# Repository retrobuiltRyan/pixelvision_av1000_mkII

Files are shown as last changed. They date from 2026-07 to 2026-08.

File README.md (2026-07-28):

# PixelVision_AV-1000_MkII

Desktop sized multi-format video display monitor for HDMI and legacy analog video input with built-in speakers.
Watch the video: (assembly section @14:51) <br>
<a href="https://youtu.be/h4x5J-W30Yo" target="_blank">
  Watch the video on YouTube
</a> ## https://youtu.be/MTYouu-5v1Q <br> 
Monitor Assy <br>
## Hardware Overview

| Specification | Details |
|---|---|
| Viewable Size | 9.7” [4:3 ratio] |
| Input Signals | HDMI [2048×1536]; VGA [1920×1080]; YPbPr, S-video, Composite [480p] |
| Audio Input/Output | Analog 3.5mm stereo |
| Speaker Output | Stereo (5 watt) |
| Power Consumption | 10 watts (2w standby) |
| Dimensions (W × H × D) | 248 × 205 × 192 mm (9.76 × 8.07 × 7.56 inches) |
| Weight | 1350 g |

### IPS [iPad 3/4] Panel Details

| Specification | Details |
|---|---|
| Pixel Density | 264 PPI |
| View Angle | 89/89/89/89 (Typ.) (CR ≥ 10) |
| Frequency | 60 Hz |
| Panel Type / Model | a-Si TFT-LCD, LCM / LP097QX1-SPC1 |
| Brightness | 440 cd/m² |

## Electrical Diagram
 <br>

## Bill of Materials
| Item | Description | Vendor Link | Cost/each (USD) | Qty | Line Total (USD) |
|---|---|---|---:|----:|---:|
| 1 alt | Speaker Dayton Audio CE32A-4 1-1/4" | [parts-express](https://www.parts-express.com/Dayton-Audio-CE32A-4-1-1-4-Mini-Speaker-4-Ohm-285-103) | 3.58 | 2 | $7.16 |
| 1 | Speaker Visaton FR7-4 2.5" | [parts-express](https://www.parts-express.com/Visaton-FR7-4-2-1-2-Full-Range-Driver-4-Ohm-292-638) | 6.47 | 2 | $12.94 |
| 2 | LCD 9.7" 2048×1536 HDMI | [aliexpress](https://www.aliexpress.us/item/3256803412961622.html) | 50.60 | 1 | $50.60 |
| 3 | Scan Line Converter | [aliexpress](https://www.aliexpress.us/item/3256805577379481.html) | 47.64 | 1 | $47.64 |
| 4 | M2.6 × 10mm Thread Forming Screw | [aliexpress]([#](https://www.aliexpress.us/item/3256807955659503.html)) | 0.04 | 70 | $2.80 |
| 5 | M3 × 6mm Button Head Screws | any | 0.03 | 3 | $0.09 |
| 6 | M3 × 11mm F/F Standoff | any | 0.10 | 3 | $0.30 |
| 7 | Filament, 1 gram PLA | any | 0.02 | 877 | $17.54 |
| 8 | Audio Amp PAM8406 | [aliexpress](https://www.aliexpress.us/item/3256807320222817.html) | 6.48 | 1 | $6.48 |
| 9 | M6 × 30 Steel Phillips Flat Head Screw | [mcmaster](https://www.mcmaster.com/91420A438/) | 0.13 | 1 | $0.13 |
| 10 | M6 Nylon Lock Nut | [mcmaster](https://www.mcmaster.com/90631A114/) | 0.08 | 1 | $0.08 |
| 11 | HDMI Super Slim Cable, 1 ft | [parts-express](https://www.parts-express.com/Audtek-TS1-1-ft.-Super-Slim-Ultra-HD-HDMI-2.0-Cable-4K60-Hz-HDR-YCbCr-444-18-Gbps-180-1318) | 3.97 | 1 | $3.97 |
| 12 | Audio Cable, Slim, 1 ft, 3.5mm | [parts-express](https://www.parts-express.com/3.5mm-Male-to-Male-Slim-Plug-Shielded-Audio-Cable-1-ft.-240-051) | 1.59 | 1 | $1.59 |
| 13 | DC Power Jack, Panel Mount (2.1 × 5.5mm) | [aliexpress](https://www.aliexpress.us/item/3256808307457555.html) | 0.45 | 2 | $0.90 |
| 14 | Rocker Switch panel mount (19 x 13mm) | [parts-express](https://www.parts-express.com/SPST-Miniature-Rocker-Switch-060-670) or [digikey](https://www.digikey.com/en/products/detail/e-switch/RA11131121/2720267) | 1.40 | 1 | $1.40 |
| 15 | Audio PCB (optional, but helpful) | custom DIY | 2.00 | 1 | $2.00 |
| 16 | Power PCB (optional, but helpful) | custom DIY | 3.00 | 1 | $3.00 |
| 17 | Rubber Feet (2 × 10mm), Round | [aliexpress](https://www.aliexpress.us/item/3256801658571146.html) | 0.10 | 4 | $0.40 |
| 18 | 12V 3A DC Power Supply (2.1 × 5.5mm) | [parts-express](https://www.parts-express.com/12V-DC-3A-AC-Adapter-Power-Supply-with-2.1-x-5.5mm-Center-Positive-Tip-with-Polarized-AC-Co-129-1204) | 7.00 | 1 | $7.00 |
| 19 | Perler Beads (plastic M2.5 washers) | any | 0.01 | 30 | $0.30 |
| 20 | Compression Spring, ~10mm OD, 25-35mm length, ~0.8mm wire dia, SS | any | 0.50 | 1 | 0.50|
| 21 | Electronics incidentals: wire, heat shrink, that one drop of hot glue | [any](#) | 1.00 | 1 | $1.00 |
| | **TOTAL** | | | | **$167.82** |

## Special Tools
You need a long reach (min 100mm) Torx T8 drive [like this](https://www.aliexpress.us/item/3256805848633499.html). If you source different M2.6 thread forming screws, then you need that matching (min 100mm long) bit drive tool .
 <br>

## 3D Printing 
These parts need to be printed. 15% infill, tree supports where applicable. <br>
*The two thin brackets that push the LCD against the front bezel are a mirrored pair. You need to clone + mirror in your slicer.* <br>

<br>

 *Critical Tip!* <br>  Absolutely block supports in blind screw holes. 


| Filament totals | Grams (g) | Cost/gram | Line total | Print time (hrs) |
|---|---:|---:|---:|---:|
| Body Rear | 416 | $0.02 | $8.32 | 14 |
| Body Front Bezel | 146 | | $2.92 | 3.75 |
| Yoke bulge | 65 | | $1.30 | 2.75 |
| LCD bracket | 42 | | $0.84 | 1 |
| Electronics Mount | 26 | | $0.52 | 1 |
| IO panel | 16 | | $0.32 | 0.75 |
| Speaker, LCD brackets (x2) + buttons | 36 | | $0.72 | 1.55 |
| Swivel Base | 130 | | $2.60 | 5 |
| **Total** | **877** | | **$17.54** | **29.8** |

## PCBs 
(optional, but very helpful with internal wiring and matching the build shown in the video)
P1130062

#### Fits this LCD panel (ipad 3/4 replacement screen):


## Support Me
If you want to support me and future work consider a [donation](https://www.paypal.com/donate/?hosted_button_id=JNT5P3N3XAK2E).
**You can also purchase a basic [fastener kit for this project](https://www.ebay.com/itm/147443247342).** This directly supports me, saves you some time sourcing parts, and clears out my surplus junk from the design process. 
small
<br>
Need a full-time hardware engineer? Hire me. DM me on twitter [@retrobuiltgames](https://x.com/retrobuiltgames)

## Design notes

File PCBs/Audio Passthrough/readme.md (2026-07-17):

Place all three kicad files (.kicad_pcb, .kicad_sch, .kicad_pro) in a folder of the same name. Open the project file (.kicad_pro) with KiCad.

- **2-in-1 PCB Application**
  - **Option 1:** TRS audio passthrough
  - **Option 2:** Ground loop isolator
  <br>

For the PixelVision AV-1000, we just need a simple 3.5mm TRS audio jack passthrough to reroute signals in the monitor enclosure. The bottom jumpers on the PCB must be soldered if this PCB is being used as a straight audio passthrough only. The board also doubles as a ground loop isolator using not-so-great audio transofrmers. (I use a ground loop isolator when I pull analog audio from a Raspberry Pi 3, which has some noisy analog audio.) From my 'raw ear listening' testing, you can't tell how the cheap these parts are. The 65mm diameter speakers cannot output freq under 100Hz, which doesnt matter as the cheap audio transformers cannot pass anything below 200Hz. That sub 200Hz roll-off numbers might be a lie one the datasheet- the parts are so cheap. 

Ground Loop isolator audio passthrough PCB <br>
Ground Loop isolator audio passthrough PCB 2 <br>

P1120733 <br>

| Reference | Quantity | DigiKey P/N |
|---|---:|---|
| J1, J2 | 2 | CP1-3523N-ND |

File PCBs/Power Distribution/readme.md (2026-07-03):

Place all three kicad files (.kicad_pcb, .kicad_sch, .kicad_pro) in a folder of the same name. Open the project file (.kicad_pro) with KiCad.

Power Dist PCB

Handles input power distribution, power on/off switching, and power rerouting. Board includes two 5 V linear regulators and one adjustable buck converter.

 ## Bill of Materials
 | Reference | Value | Qty | DigiKey P/N |
|-----------|-------|----:|-------------|
| C1, C3, C5 | 0.22uF 50V CER | 3 | 445-2283-1-ND |
| C2, C4, C6 | 0.1uF 50V | 3 | 1276-1068-1-ND |
| D1 | DIODE STANDARD 50V 5A SMC | 1 | S5AC-FDICT-ND |
| J1, J2, J3, J4, J5, J6, J7 | Screw_Terminal_2_P3.50mm | 7 | 732-2747-ND |
| R3, R5, R6 | 330 | 3 | 311-330FRCT-ND |
| U2 | LM7809_TO220 | 1 | BA7809FP-E2CT-ND |
| U3 | L7805 | 1 | 497-7255-1-ND |
| U4 | Adj Buck Converter | 1 | [AliExpress](https://www.aliexpress.us/item/3256805684077964.html) |

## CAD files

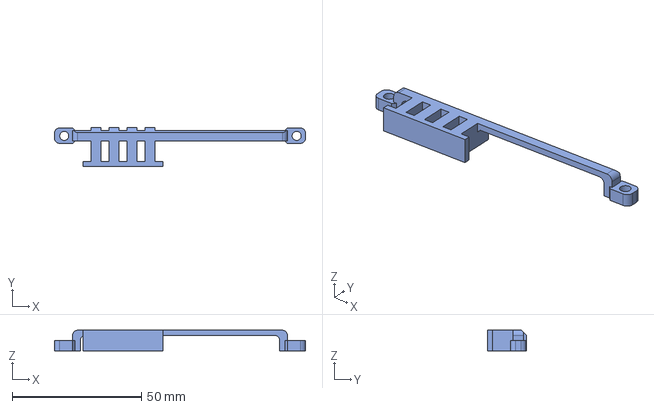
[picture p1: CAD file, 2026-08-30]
STEP files/PixelVision AV-1000MkII v1.0 Swivel Base - LightPipe clip.step
97.2 x 15.2 x 8.00 mm

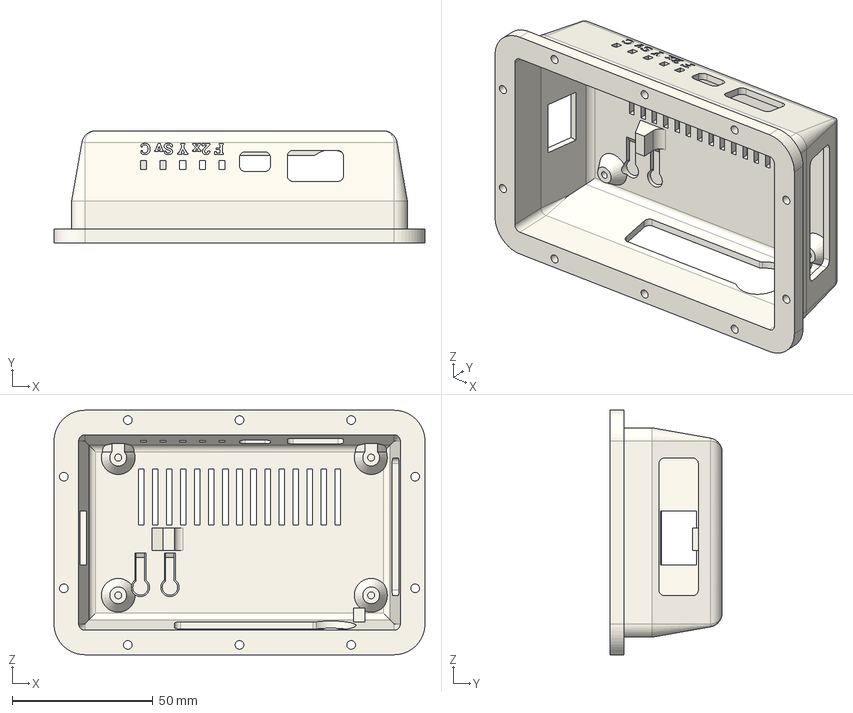
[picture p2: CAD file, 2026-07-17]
STEP files/PixelVision AV-1000MkII v1.0 - Yoke Buldge.step
132.0 x 40.0 x 87.0 mm

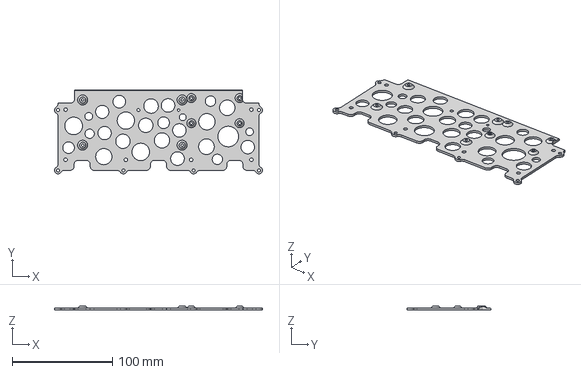
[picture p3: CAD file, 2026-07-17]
STEP files/PixelVision AV-1000MkII v1.0 - Electronics mount.step
207.0 x 83.4 x 4.00 mm

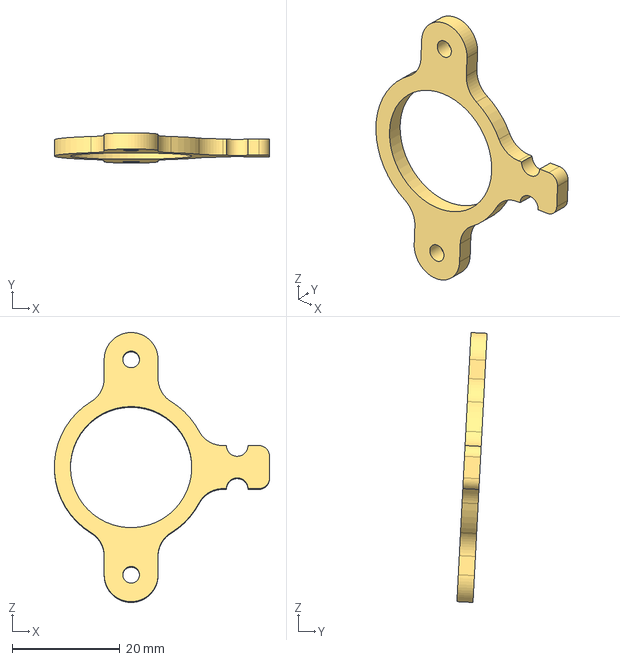
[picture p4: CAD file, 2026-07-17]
STEP files/PixelVision AV-1000MkII v1.0 - Speaker Bracket Small.step
39.9 x 5.61 x 50.1 mm

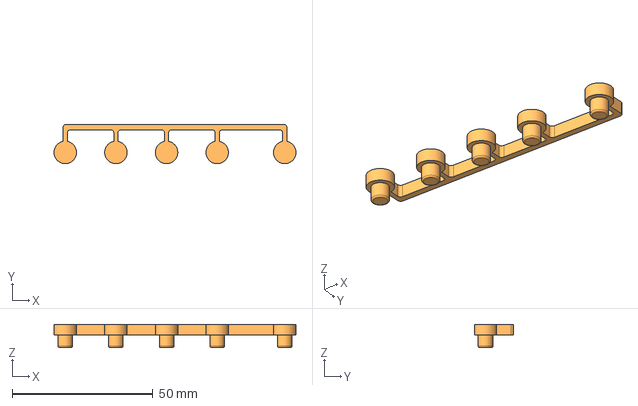
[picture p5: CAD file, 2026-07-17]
STEP files/PixelVision AV-1000MkII v1.0 - Buttons finglonger.step
86.0 x 14.0 x 8.25 mm

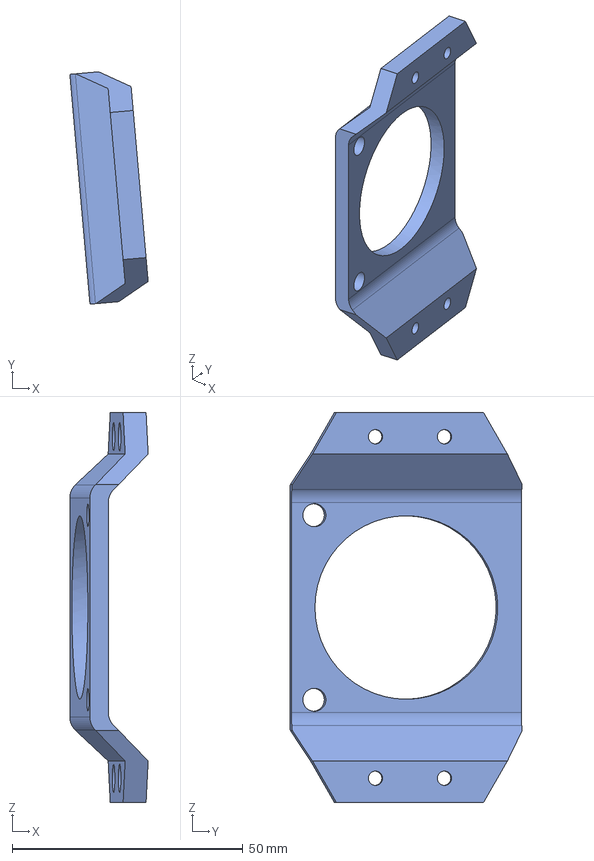
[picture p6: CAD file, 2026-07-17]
STEP files/PixelVision AV-1000MkII v1.0 - Speaker Bracket Large.step
17.0 x 50.4 x 84.5 mm

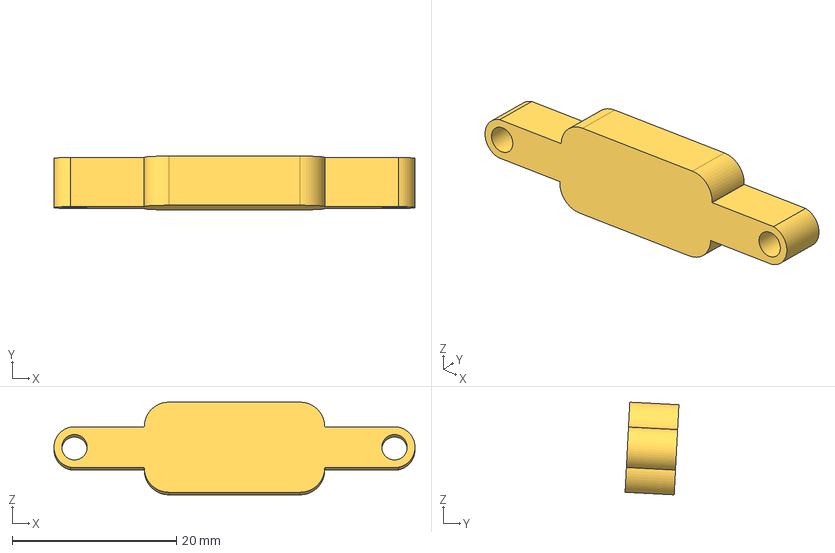
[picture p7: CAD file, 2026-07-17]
STEP files/PixelVision AV-1000MkII v1.0 - LCD ribbon pcb bracket.step
44.0 x 6.57 x 11.3 mm

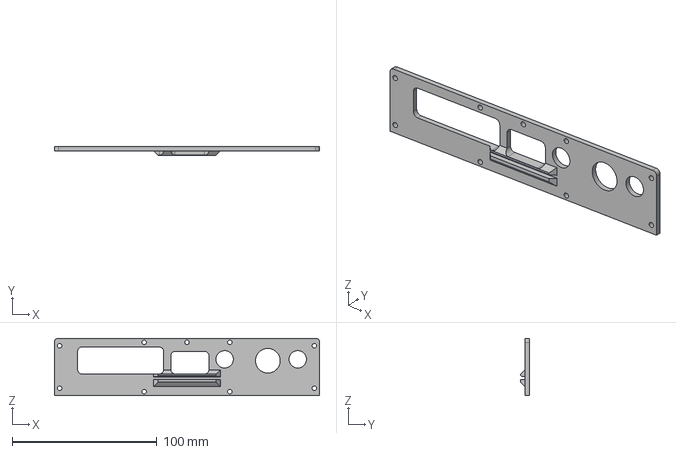
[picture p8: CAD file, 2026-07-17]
STEP files/PixelVision AV-1000MkII v1.0 - IO Cover Plate (rear).step
182.9 x 6.00 x 39.6 mm

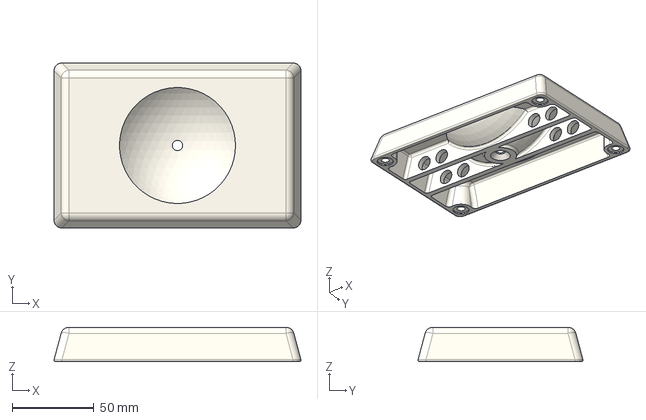
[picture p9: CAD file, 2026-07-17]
STEP files/PixelVision AV-1000MkII v1.0 Swivel Base - Bot.step
150.6 x 100.6 x 21.0 mm

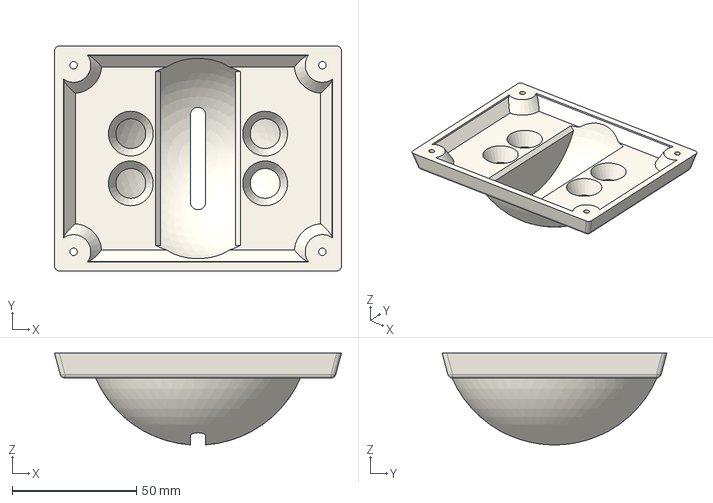
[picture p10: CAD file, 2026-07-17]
STEP files/PixelVision AV-1000MkII v1.0 Swivel Base - Top.step
115.4 x 90.4 x 36.9 mm

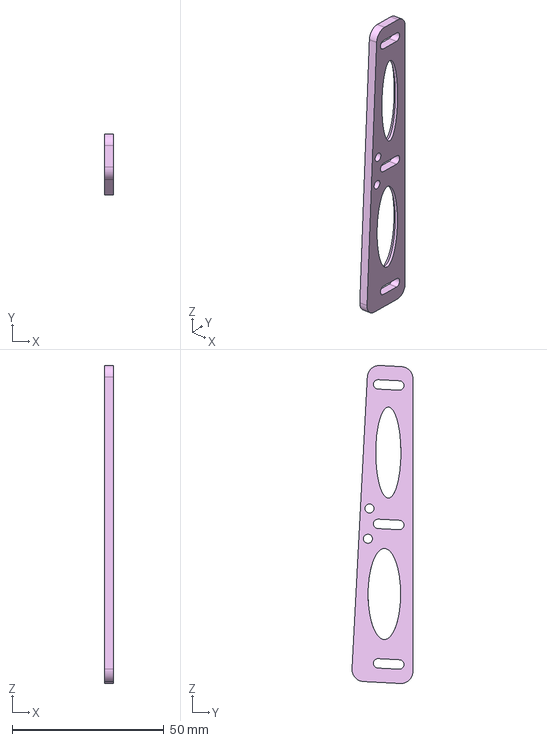
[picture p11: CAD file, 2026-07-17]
STEP files/PixelVision AV-1000MkII v1.0 - LCD retention bracket.step
3.00 x 20.1 x 104.9 mm

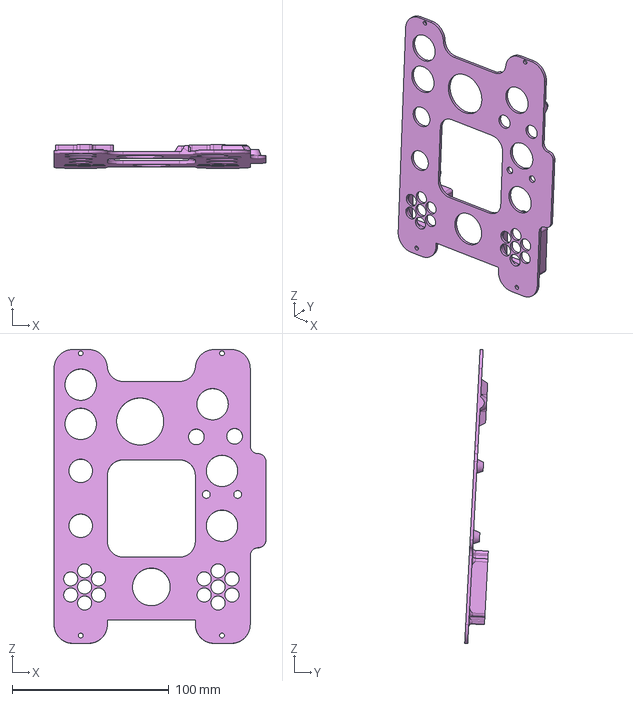
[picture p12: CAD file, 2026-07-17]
STEP files/PixelVision AV-1000MkII v1.0 - LCD rear support.step
135.0 x 15.1 x 187.3 mm

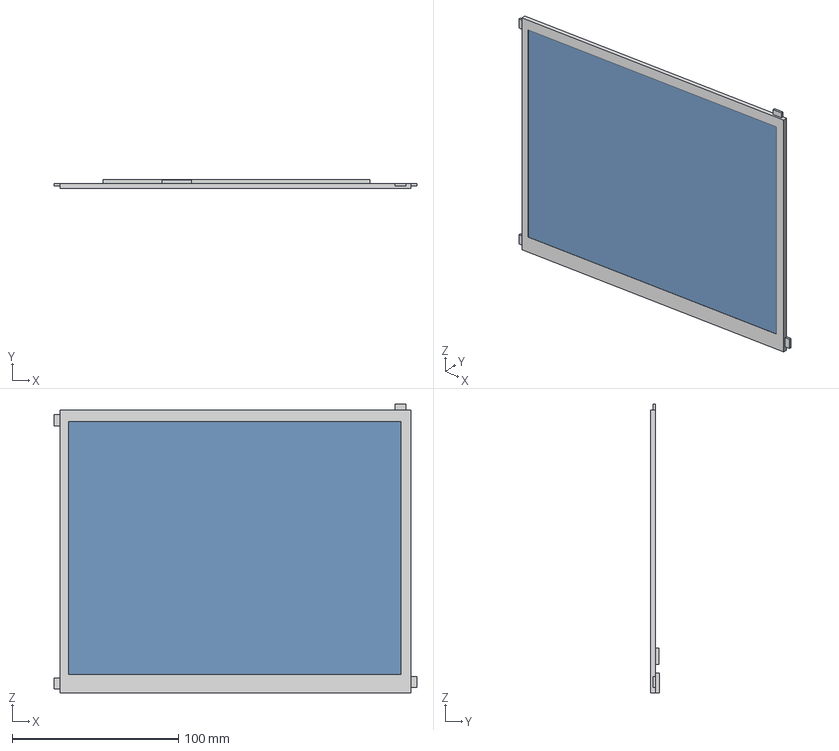
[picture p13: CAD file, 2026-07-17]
STEP files/9.7in IPS LCD.step
218.2 x 5.15 x 173.6 mm

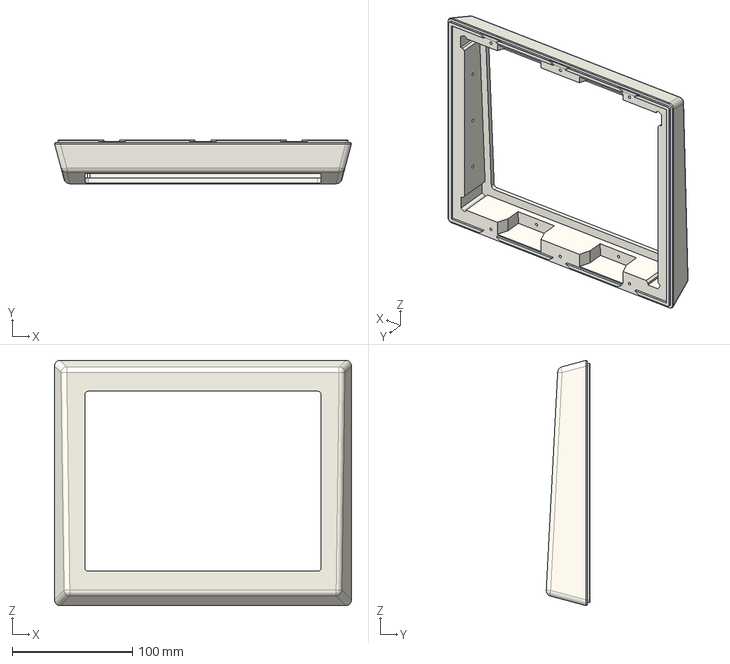
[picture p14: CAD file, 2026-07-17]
STEP files/PixelVision AV-1000MkII v1.0 - Front Bezel.step
247.5 x 36.3 x 204.5 mm

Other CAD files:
STEP files/PixelVision AV-1000MkII v1.0 - Rear Body.step
STEP files/PixelVision AV-1000MkII v1.0 Swivel Base - Spring Nut.step
STEP files/PixelVision AV-1000MkII v1.0 Swivel Base - Curve Washer.step
3D Print Files/PixelVision AV-1000MkII v1.0 - Buttons finglonger.3mf
3D Print Files/PixelVision AV-1000MkII v1.0 - Electronics mount.3mf
3D Print Files/PixelVision AV-1000MkII v1.0 - Front Bezel.3mf
3D Print Files/PixelVision AV-1000MkII v1.0 - LCD retention bracket.3mf
3D Print Files/PixelVision AV-1000MkII v1.0 - LCD ribbon pcb bracket.3mf
3D Print Files/PixelVision AV-1000MkII v1.0 - Rear Body.3mf
3D Print Files/PixelVision AV-1000MkII v1.0 - Speaker Bracket Large.3mf
3D Print Files/PixelVision AV-1000MkII v1.0 - Speaker Bracket Small.3mf
3D Print Files/PixelVision AV-1000MkII v1.0 - Yoke Buldge.3mf
3D Print Files/PixelVision AV-1000MkII v1.0 Swivel Base - Bot.3mf
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

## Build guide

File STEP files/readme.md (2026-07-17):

All step files for 3D printable part I designed. The IPS LCD screen is also included as reference for new or remix designs. <br>
Monitor Assy
Do not upload these to any other file hosting site or 3D print repository site.

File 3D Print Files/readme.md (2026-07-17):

3D printable files. <br>


*Do not upload these to any other file hosting site or 3D print repository site.*

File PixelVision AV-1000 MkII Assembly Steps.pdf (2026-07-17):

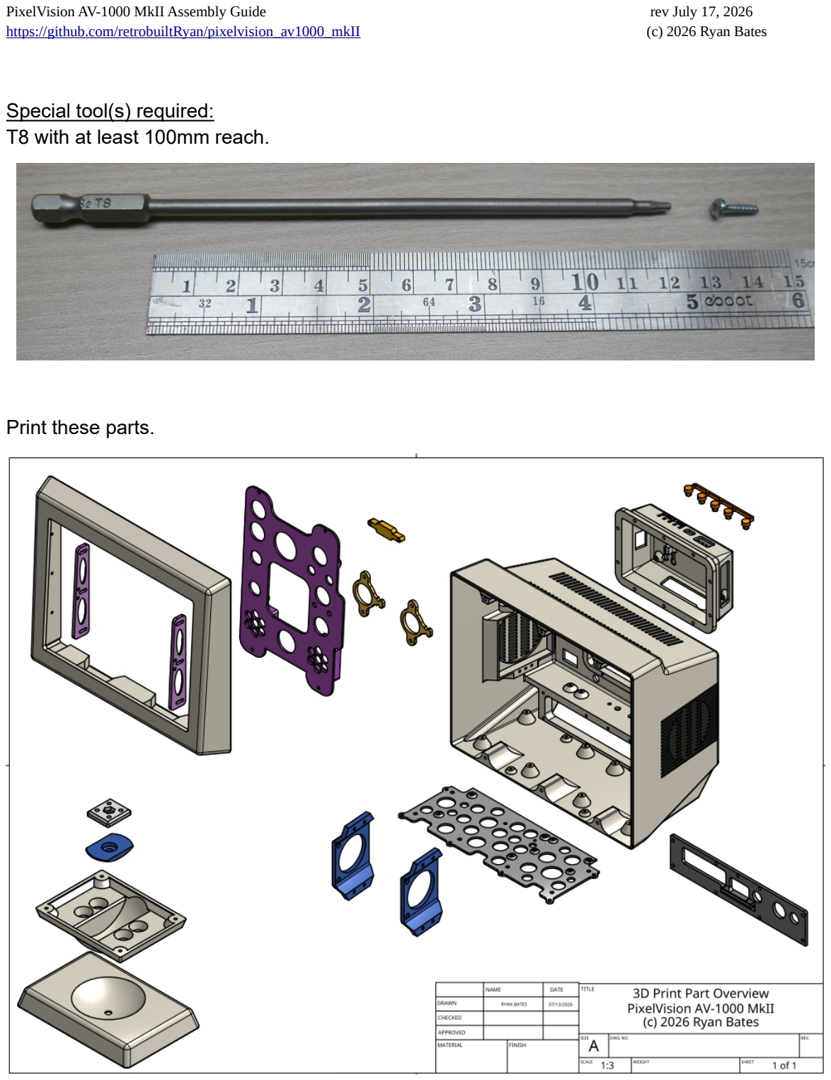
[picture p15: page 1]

PixelVision AV-1000 MkII Assembly Guide | rev July 17, 2026
https://github.com/retrobuiltRyan/pixelvision_av1000_mkII | (c) 2026 Ryan Bates

Special tool(s) required:
T8 with at least 100mm reach.

Print these parts.

step | Assembly description | Visual | ✅
1 | Prep printed parts. Remove supports and webbing. Debur edges where required.

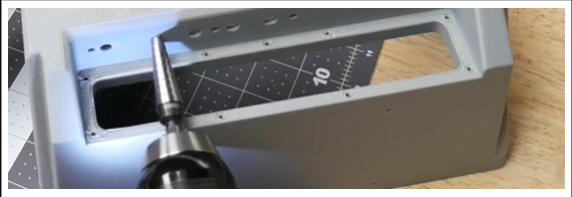
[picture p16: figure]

2 | Drill out to ~5mm rear button holes for monitor control button extenders.
3 | Insert button extenders.
4 | Add mounting stand off (10mm) to button panel and install in rear with M3 button head fasteners. (Note: stand-offs are not shown in this diagram)
5 | Note: Some LCD driver PCBs have headers for speakers and power input. A mating connector can be used, but in this example I am soldering to the underside of the these connectors.
6 | Solder a 30cm leads to the +12V and GND pads on underside of the LCD driver board. Make note of the polarity.

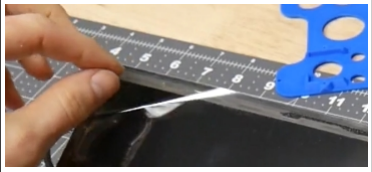
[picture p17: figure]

7 | Remove the LCD’s protective plastic.

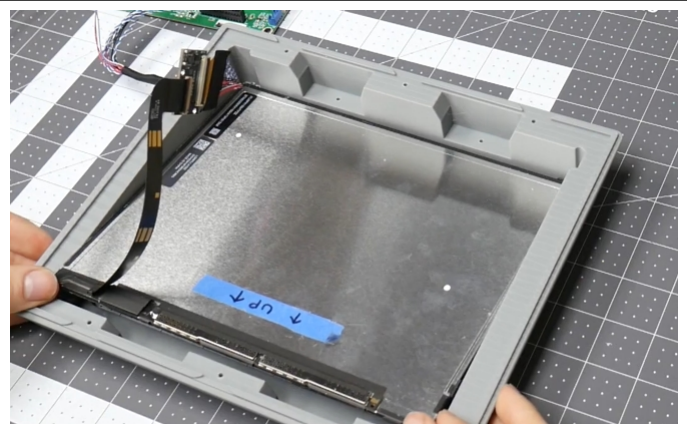
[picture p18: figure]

8 | Carefully place the LCD intro front bezel. It is recommended you tape a piece of cardboard to the front bezel to avoid accidentally scratching the LCD.

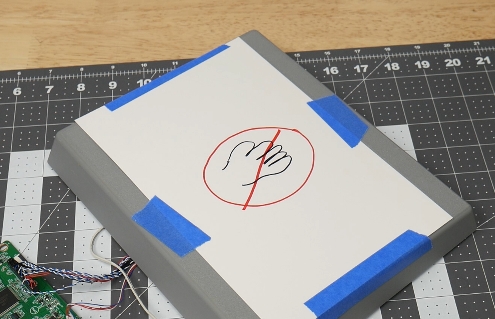
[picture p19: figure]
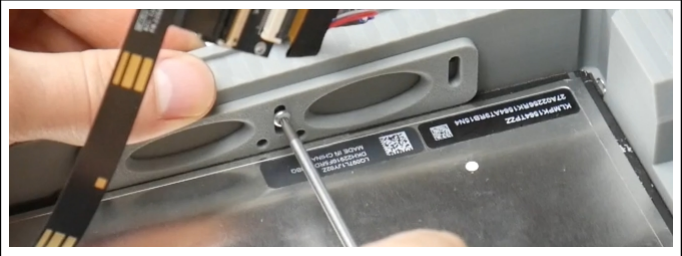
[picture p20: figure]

9 | Fasten with side brackets. Ensure the brackets apply gentle pressure, pushing the screen against the bezel. The two dots on the bracket should be adjacent to LCD.

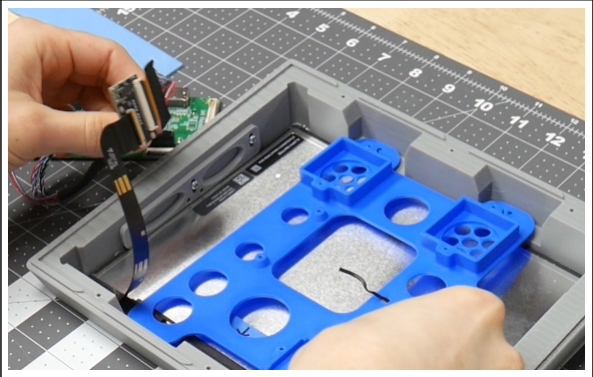
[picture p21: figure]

10 | Gently life the LCD panel’s ribbon cable out of the way. Add rear mounting panel. Fasten with screws.

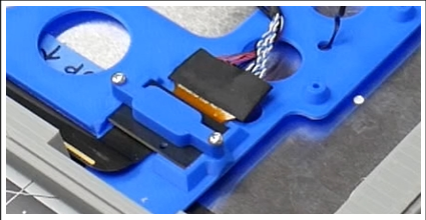
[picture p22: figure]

11 | Carefully place the ribbon cable PCB into the cavity. Add the bracket and fasten with screws.

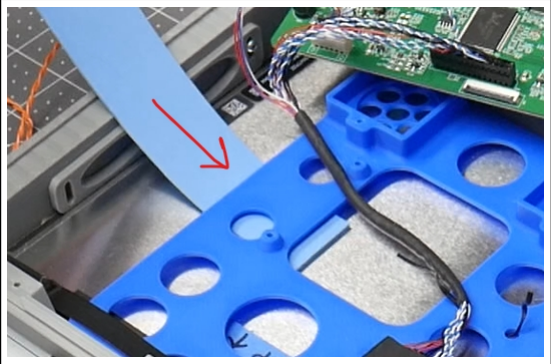
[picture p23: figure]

12 | Optional: Craft foam (~2mm thick) can be placed behind the bracket to prevent the LCD panel from bowing inward.

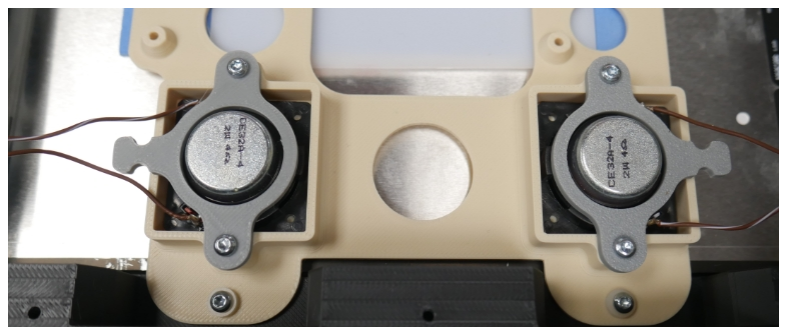
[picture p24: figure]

13 | Solder ~20cm leads to speakers, place the speakers into the openings. Add the retention brackets and fasten with screws.

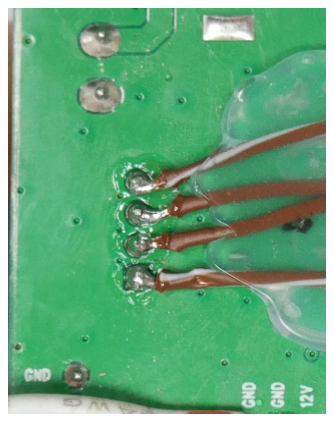
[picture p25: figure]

14 | Solder the the L-/+ and R-/+ channels to the rear of the LCD driver board.
15 | Mount the power regulator board to the LCD panel bracket.

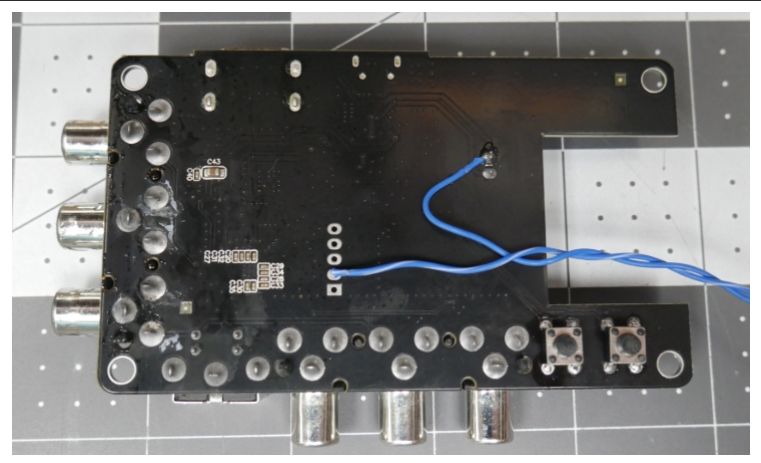
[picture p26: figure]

16 | Disassemble the video scaler. Save the light pipe for later. Remove the video scaler’s function buttons. Solder these two buttons to the reverse (bottom) side of the PCB. Solder two leads to the +5 and GND pads. Make note of polarity.

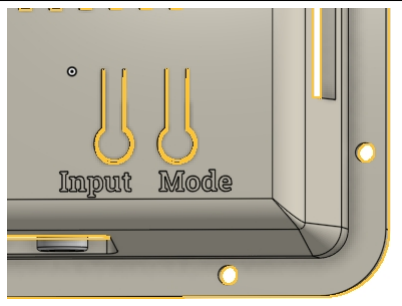
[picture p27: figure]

17 | Check the clearance between the button and the flexture tabs of the yoke bulge. Use a lighter flame to heat the plastic and bend the tabs so they do not push on the buttons. Note: The buttons can be trimmed with pliers instead of doing this step.

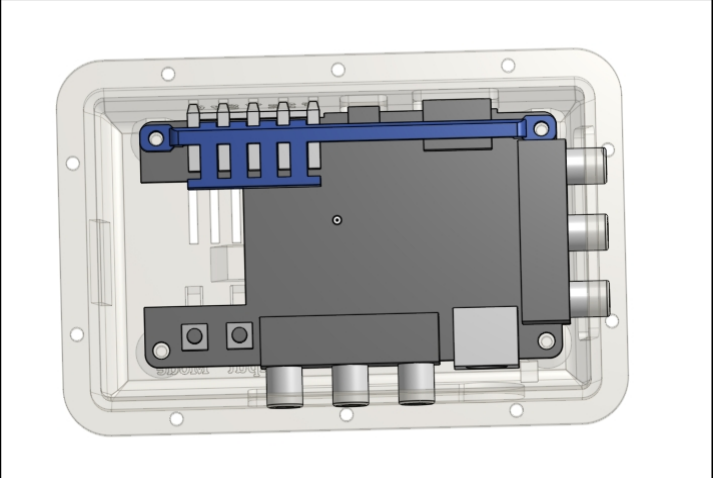
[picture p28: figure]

18 | Install the scaler into the yoke shell, add the light pipes and light bracket. Fasten with screws.

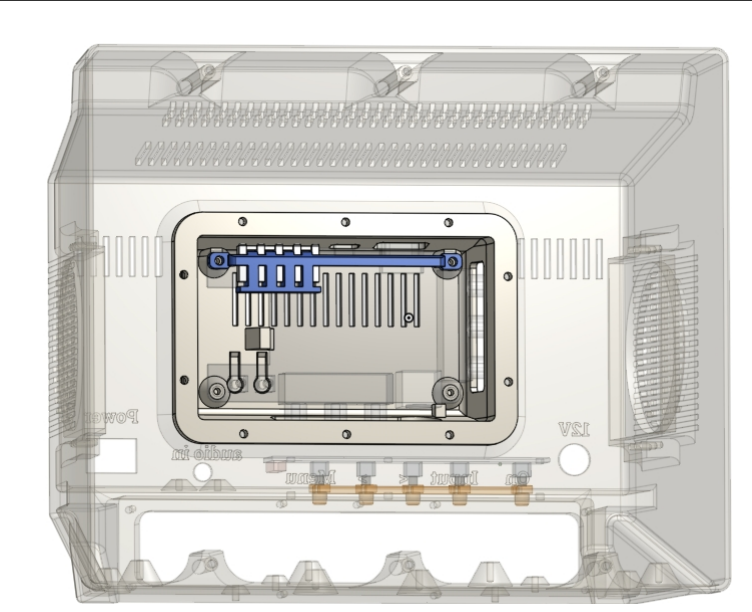
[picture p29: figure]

19 | Install the yoke assembly into the rear shell. Fasten with screws. Insert the power switch and connect it to the scaler,

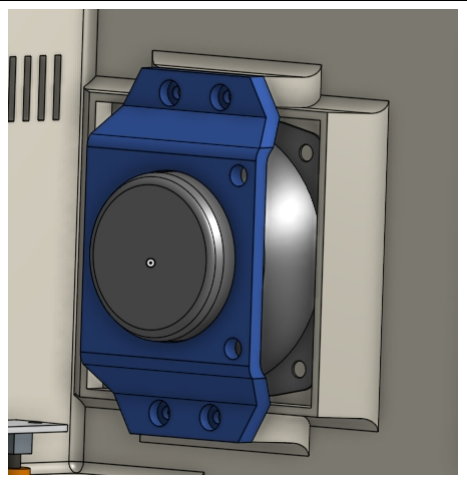
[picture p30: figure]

20 | Solder wire leads to the 2.5in speakers. Place the 2.5in speakers into the rear shell side cavities. Fasten the bracket with screws.

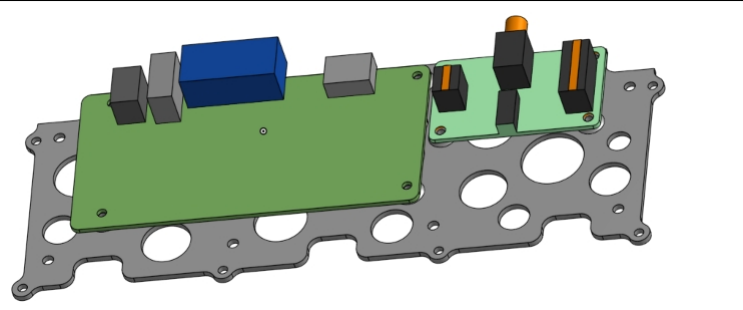
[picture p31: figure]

21 | Mount the LCD driver PCB and the optional audio amp to the electronics mounting panel. Fasten with screws.

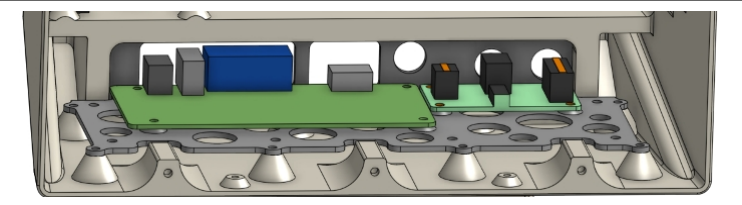
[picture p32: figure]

22 | Place this assembly into the rear shell. Fasten with screws.

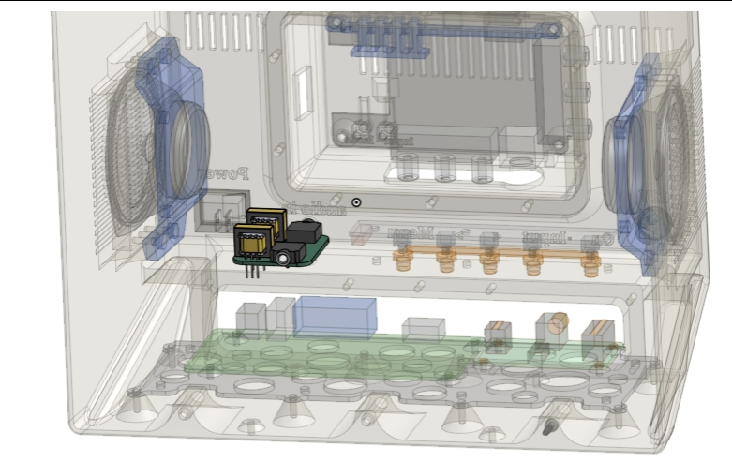
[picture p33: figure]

23 | Install the audio PCB (optional). Add the 3.5mm stereo audio cable to connect the amp to the audio pass-through.

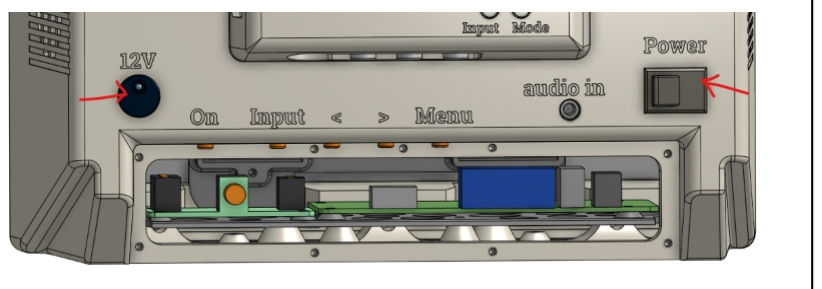
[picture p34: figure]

24 | Add rear power switch and DC jack. Install the rear io cover and the final DC power jack. Fasten with screws.

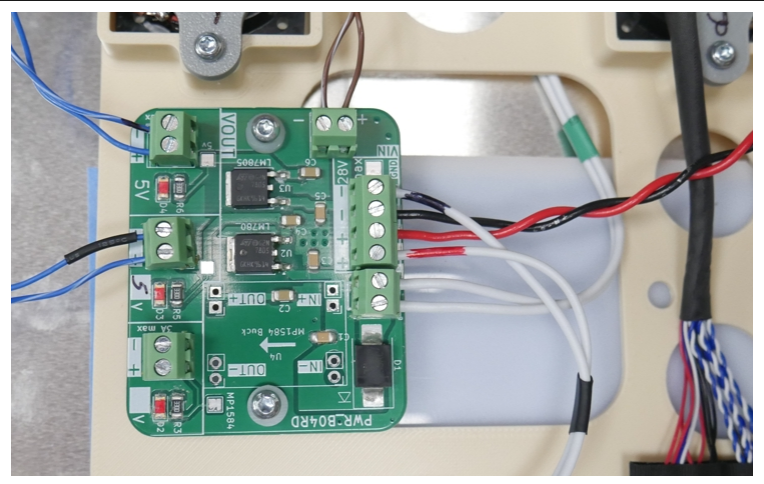
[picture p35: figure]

25 | Mount and wire all connections to power distribution board PCB. Refer to the wiring diagram at end of document.

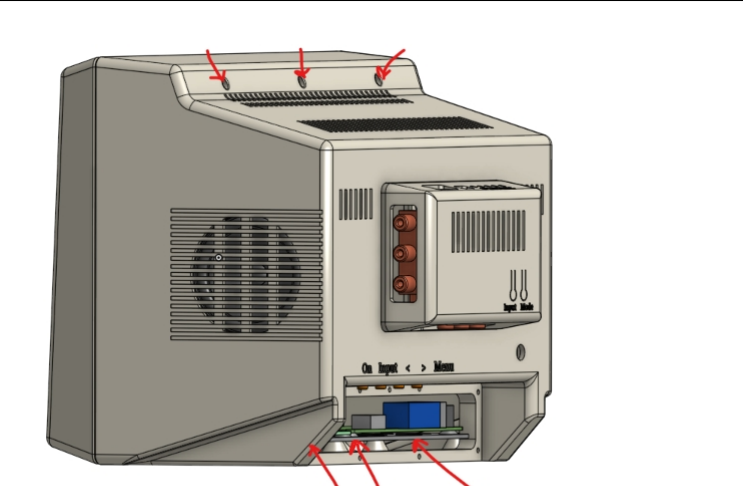
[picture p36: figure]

26 | Attached the front and rear shells. Fasten with 6 screws. A long reach (100mm) T8 bit is required for the bottom screws.

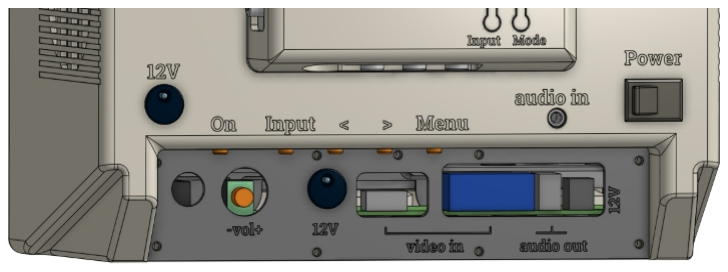
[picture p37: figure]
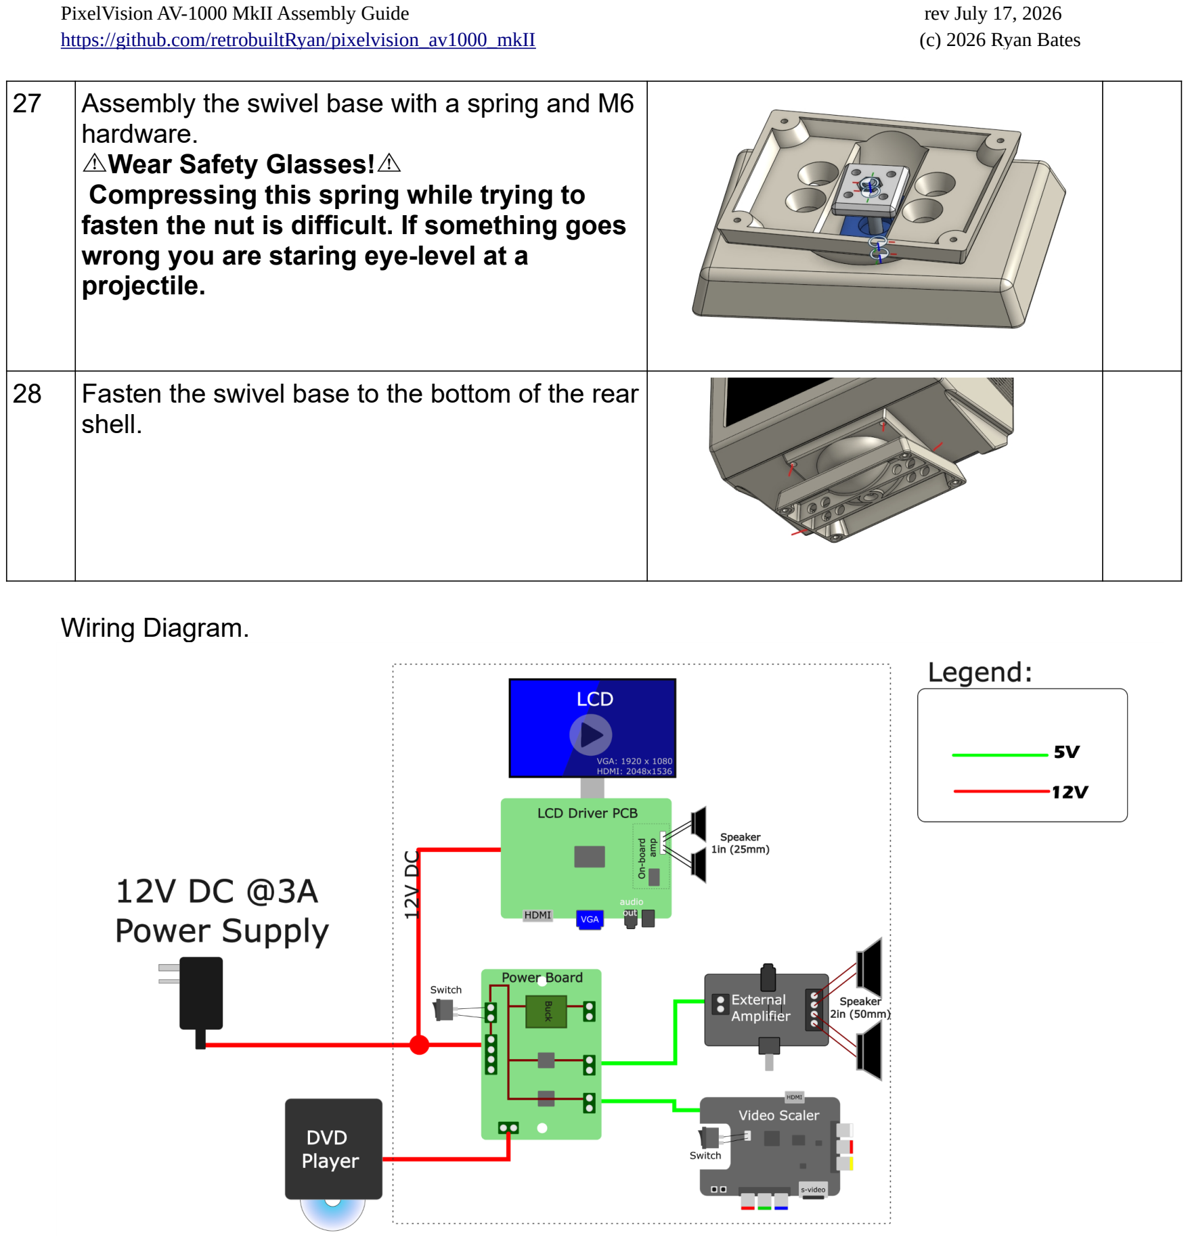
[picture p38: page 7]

27 | Assembly the swivel base with a spring and M6 hardware. ⚠️Wear Safety Glasses!⚠️ Compressing this spring while trying to fasten the nut is difficult. If something goes wrong you are staring eye-level at a projectile.
28 | Fasten the swivel base to the bottom of the rear shell.

Wiring Diagram.

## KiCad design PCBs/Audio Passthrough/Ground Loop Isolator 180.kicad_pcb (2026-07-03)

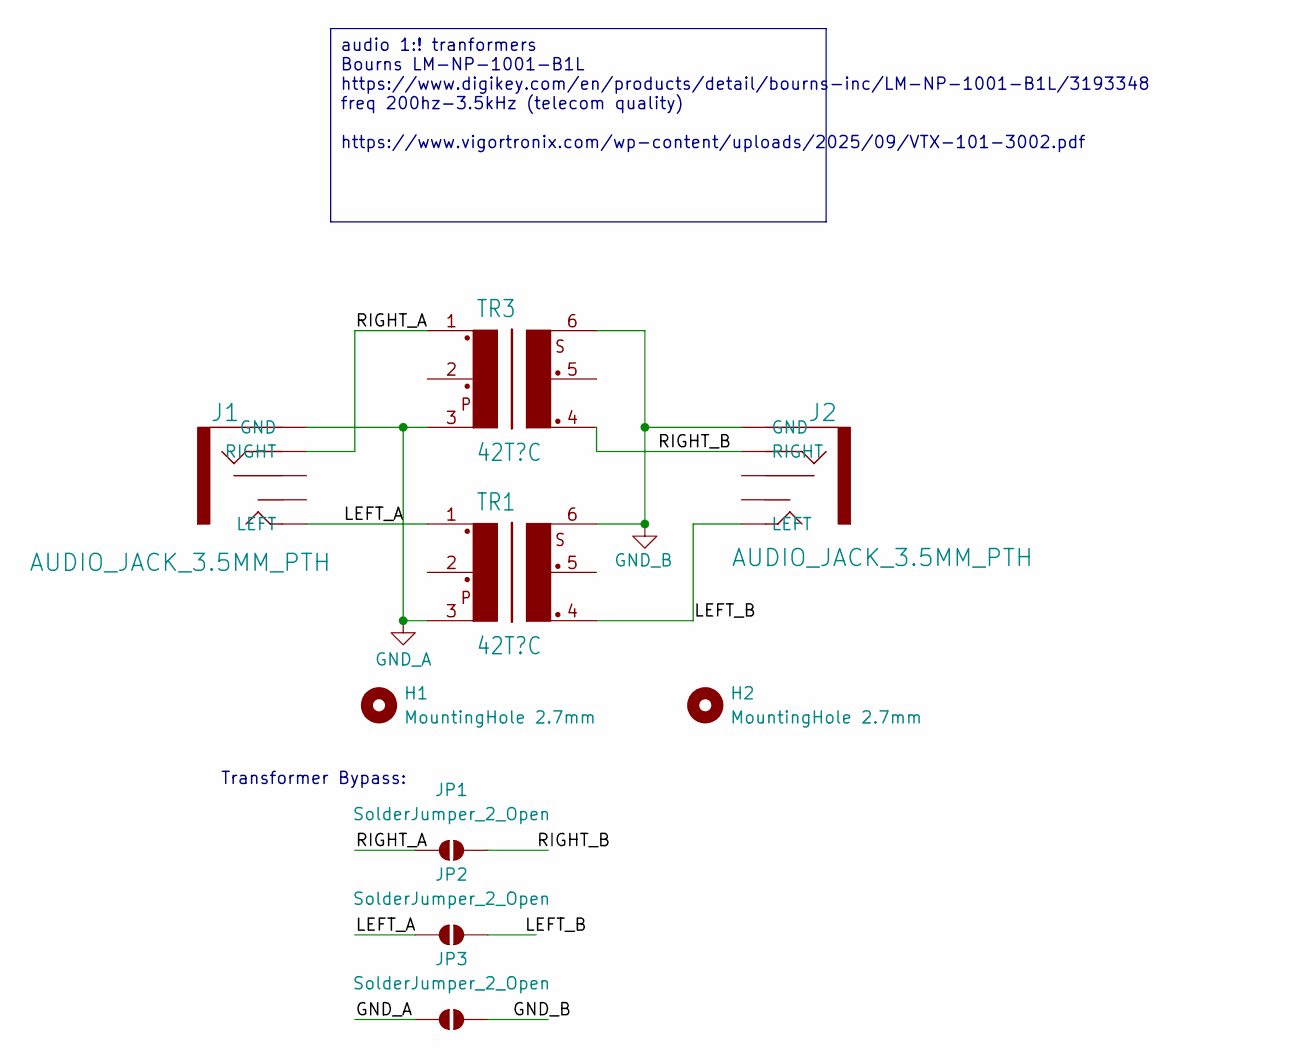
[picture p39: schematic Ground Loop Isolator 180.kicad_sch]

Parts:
H1, H2: MountingHole 2.7mm; MountingHole_2.7mm
J1, J2: AUDIO_JACK_3.5MM_PTH; AUDIO-JACK; DigiKey P/N CP1-3524NG-ND
JP1, JP2, JP3: SolderJumper_2_Open; SolderJumper-2_P2.7mm_Open_Pad2x1.5mm FAT
TR1, TR3: 42T?C; 42TC

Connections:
/LEFT_A: J1.LEFT, JP2.1 (A), TR1.1
/LEFT_B: J2.LEFT, JP2.2 (B), TR1.4
/RIGHT_A: J1.RIGHT, JP1.1 (A), TR3.1
/RIGHT_B: J2.RIGHT, JP1.2 (B), TR3.4
GND_A: J1.GND, JP3.1 (A), TR1.3, TR3.3
GND_B: J2.GND, JP3.2 (B), TR1.6, TR3.6

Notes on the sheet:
Transformer Bypass:
audio 1:! tranformers Bourns LM-NP-1001-B1L https://www.digikey.com/en/products/detail/bourns-inc/LM-NP-1001-B1L/3193348 freq 200hz-3.5kHz (telecom quality) https://www.vigortronix.com/wp-content/uploads/2025/09/VTX-101-3002.pdf

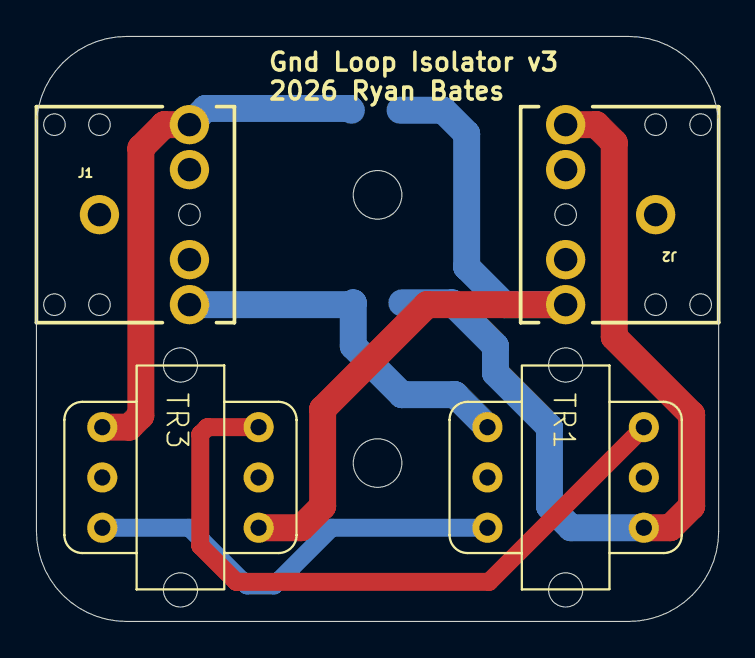
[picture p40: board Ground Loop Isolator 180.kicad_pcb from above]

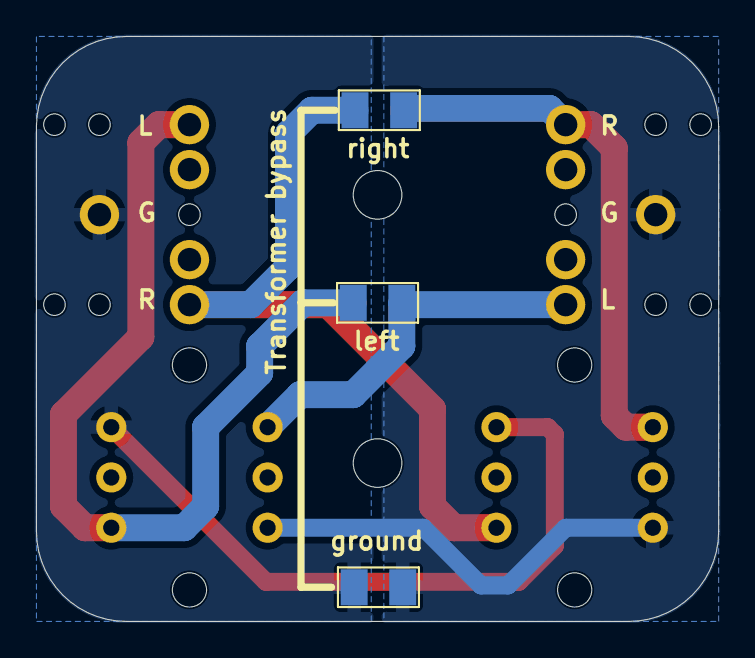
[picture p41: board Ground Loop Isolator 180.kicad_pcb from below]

Board: 2 copper layers, 37.9 x 32.5 mm, 9 parts (3 on the bottom side), 6 nets.

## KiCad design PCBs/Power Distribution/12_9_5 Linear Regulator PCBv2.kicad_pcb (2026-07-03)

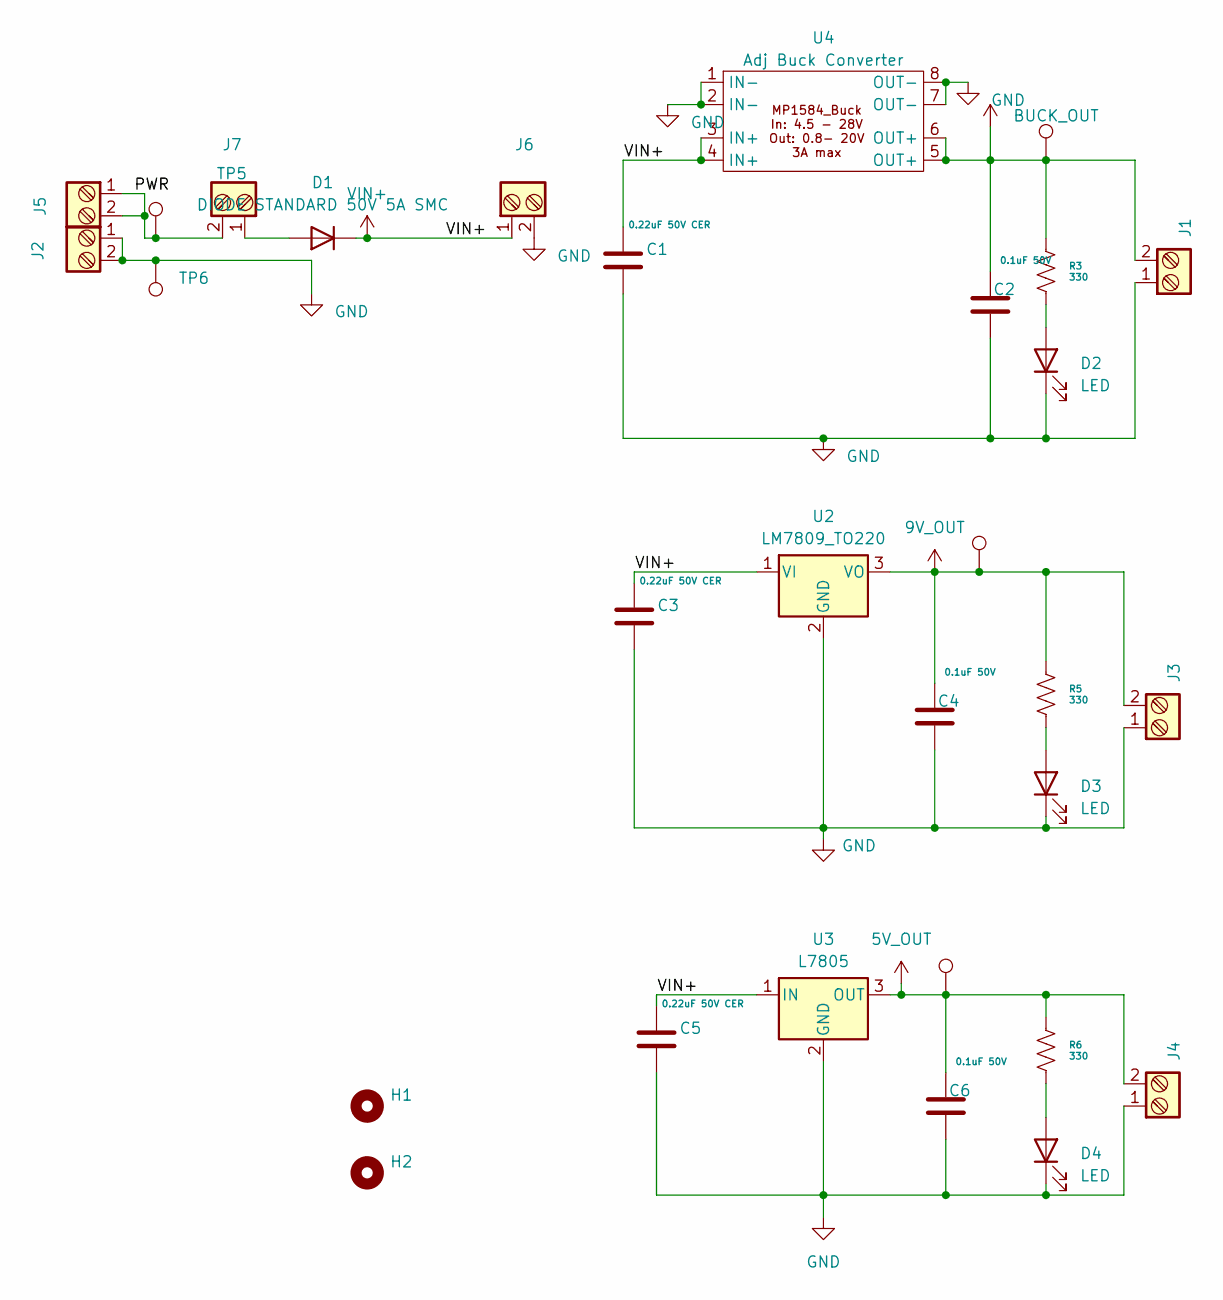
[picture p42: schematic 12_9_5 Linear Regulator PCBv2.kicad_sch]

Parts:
C1, C3, C5: 0.22uF 50V CER; C_1206_3216Metric; DigiKey P/N 445-2283-1-ND
C2, C4, C6: 0.1uF 50V; C_1206_3216Metric; DigiKey P/N 1276-1068-1-ND
D1: DIODE STANDARD 50V 5A SMC; D_SMC_Handsoldering; DigiKey P/N S5AC-FDICT-ND
D2, D3, D4: LED; LED_1206_3216Metric; DigiKey P/N 1080-1419-1-ND
H1, H2: MountingHole; MountingHole_3.2mm_M3
J1, J2, J3, J4, J5, J6, J7: Screw_Terminal_2_P3.50mm; TerminalBlock_Phoenix_PT-1,5-2-3.5-H_1x02_P3.50mm_Horizontal; DigiKey P/N 732-2747-ND
R3, R5, R6: 330; R_1206_3216Metric; DigiKey P/N 311-330FRCT-ND
TP1, TP3, TP4: uC +5V; TestPoint_Pad_2.0x2.0mm
TP5, TP6: TestPoint; TestPoint_Pad_2.5x2.5mm
U2: LM7809_TO220; TO-252-2; DigiKey P/N BA7809FP-E2CT-ND
U3: L7805; TO-252-2; DigiKey P/N 497-7255-1-ND
U4: Adj Buck Converter; MP1584

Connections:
5V_OUT: C6.1, J4.2, R6.1, TP4.1, U3.3 (OUT)
9V_OUT: C4.1, J3.2, R5.1, TP3.1, U2.3 (VO)
/PWR: J5.1, J5.2, J7.2, TP5.1
BUCK_OUT: C2.1, J1.2, R3.1, TP1.1, U4.5 (OUT+), U4.6 (OUT+)
GND: C1.2, C2.2, C3.2, C4.2, C5.2, C6.2, D2.1 (K), D3.1 (K), D4.1 (K), J1.1, J2.1, J2.2, J3.1, J4.1, J6.2, TP6.1, U2.2 (GND), U3.2 (GND), U4.1 (IN-), U4.2 (IN-), U4.7 (OUT-), U4.8 (OUT-)
unnamed: D1.2 (A), J7.1
unnamed: D2.2 (A), R3.2
unnamed: D3.2 (A), R5.2
unnamed: D4.2 (A), R6.2
VIN+: C1.1, C3.1, C5.1, D1.1 (K), J6.1, U2.1 (VI), U3.1 (IN), U4.3 (IN+), U4.4 (IN+)

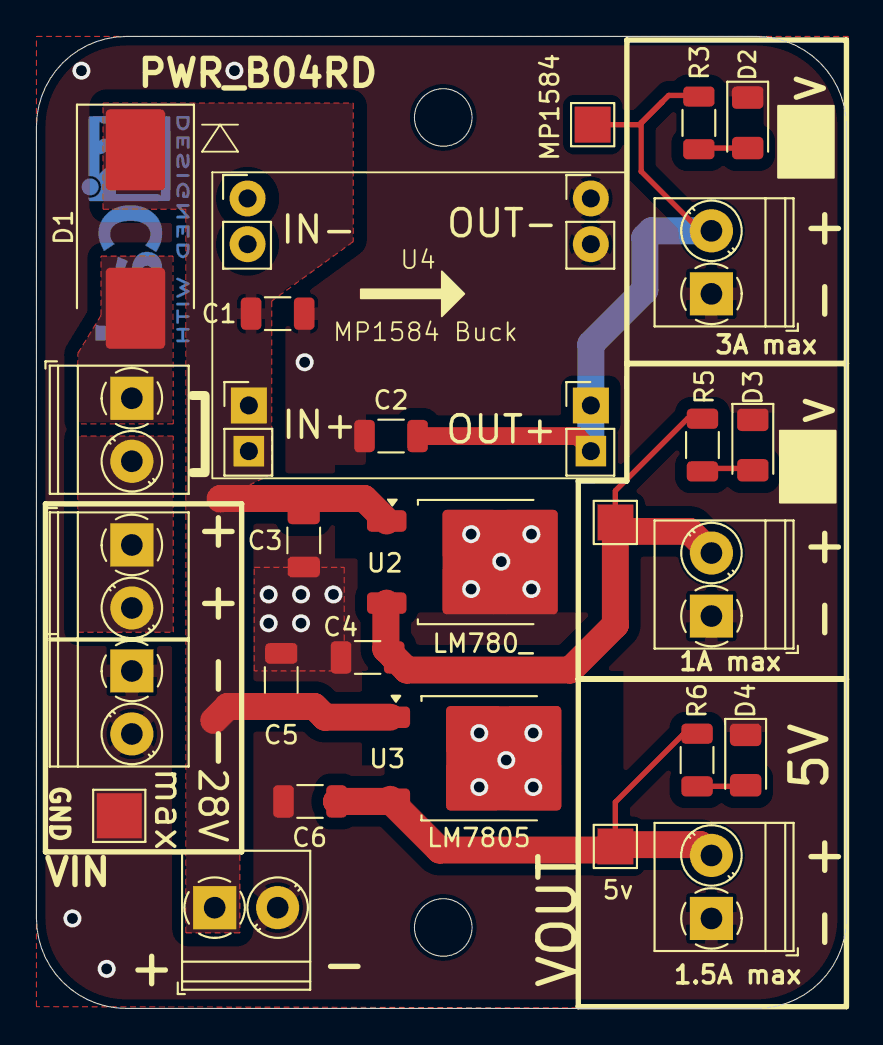
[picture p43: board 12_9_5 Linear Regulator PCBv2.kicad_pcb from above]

Board: 2 copper layers, 45.0 x 54.0 mm, 29 parts (0 on the bottom side), 10 nets.

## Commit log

2026-06-22 Update README.md
    add BoM and Printing estimates
2026-07-03 Create Power Distribution.md
2026-07-03 kicad design files rev july 20206
    [12_9_5 Linear Regulator PCBv2.kicad_pcb, 12_9_5 Linear Regulator PCBv2.kicad_sch]
2026-07-03 kicad design files rev may 2026
    [Ground Loop Isolator 180.kicad_pcb, Ground Loop Isolator 180.kicad_sch]
2026-07-13 Update README.md
    added 3d print part picture
2026-07-14 Update README.md
    BoM expansion
2026-07-14 Update README.md
    BoM total calc
2026-07-17 Update README.md
    support block in blind screw hole tip
2026-07-17 Update README.md
    compression spring add
2026-07-17 Delete PixelVision AV-1000 MkII Assembly Steps.pdf
    delete
2026-07-17 spring warning
    warning about that spring going boing into your eye. ask me how i know
2026-07-28 Update README.md
    spring wire diameter and material
